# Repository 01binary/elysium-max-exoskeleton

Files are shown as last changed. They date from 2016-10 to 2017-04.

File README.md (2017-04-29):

# Elysium Max Exoskeleton
A full-scale replica of the exoskeleton frame worn in the movie Elysium (2013) by Max Da Costa. A few parts differ from their screen appearance to introduce interesting detail but most have been modeled based on photographs and verified from several different angles.

> All STL/OBJ exports use millimeter units. Build volume is 5,592,770 mm^3.

* [Parts are viewable on GitHub](https://github.com/01binary/elysium-max-exoskeleton/blob/master/print/HipRight.stl).
* Instructions for building are included: [Default (Light)](https://github.com/01binary/elysium-max-exoskeleton/raw/master/instructions/assembly%20instructions.pdf) | [Hackaday (Dark)](https://github.com/01binary/elysium-max-exoskeleton/raw/hackadayinstructions/instructions/assembly%20instructions.pdf)
* [Follow the project on Hackaday](https://hackaday.io/project/19830-elysium-max-exoskeleton).
* [See the build log on Replica Prop Forum](http://www.therpf.com/showthread.php?t=212832).
* Interested in contributing? Fork or see the project tasks [here](https://github.com/01binary/elysium-max-exoskeleton/projects/1).

--------

* `print` - contains STL exports of individual parts
* `instructions` - contains a PDF with build instructions
    * `src` - source InDesign file w/links used to export the instructions PDF
* `assembled` - contains high-poly STL and OBJ exports for the assembled exoskeleton
* `src` - contains Autodesk Inventor parts (.ipt) and assemblies (.iam)
    * `Assemblies` - contains assemblies
        * `Pistons` - contains assemblies for each unique piston pair
    * `External` - contains parts modeled after existing real-world objects so that they can be referenced in Exoskeleton assembly
    * `Pistons` - contains piston parts
    * `Design` - contains original drawings used at starting stage of the project
* `render` - contains 3D renders to show assembled parts at a glance
* `view` - contains low-poly OBJ export of the entire exoskeleton with ambient occlusion and UV coordinates (for real-time 3D rendering)
* `build` - contains photographs to show assembled parts at a glance
* `references` - contains reference photographs used to model all parts in this project

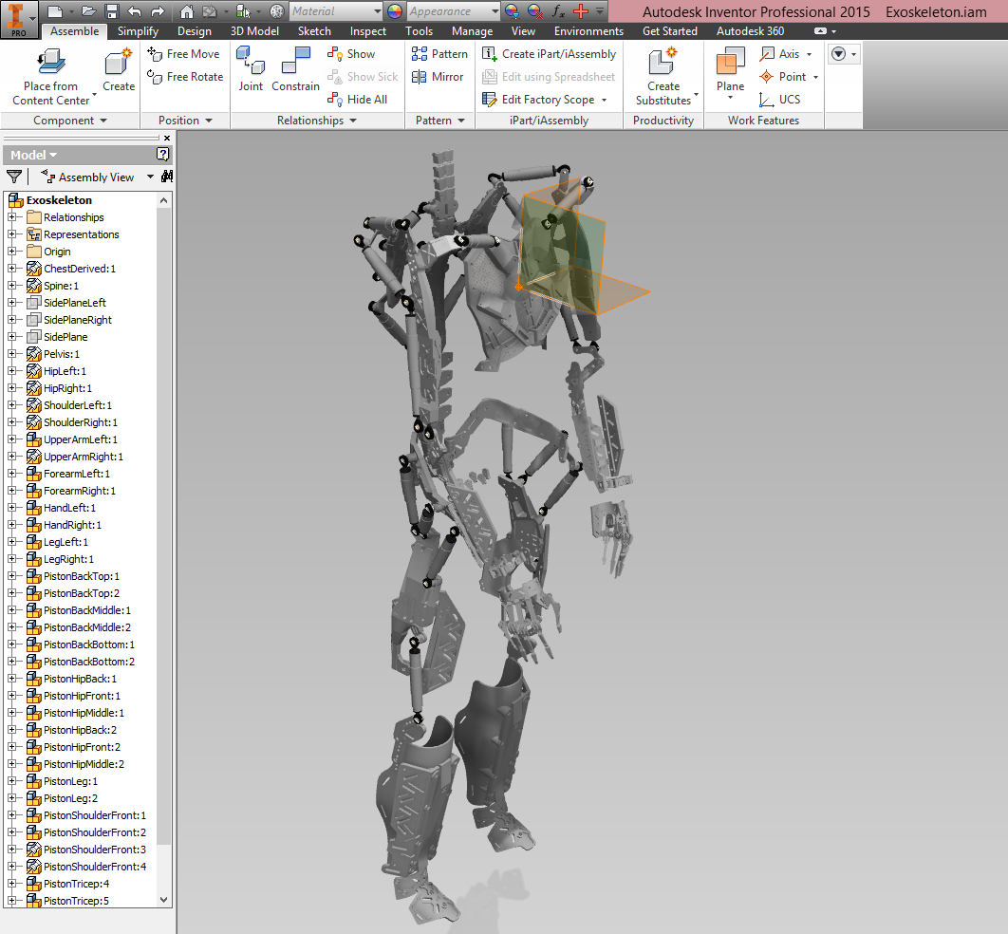
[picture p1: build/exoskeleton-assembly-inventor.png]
inventor Inventor Assembly


| Front | Side | Back |
|---|---|---|
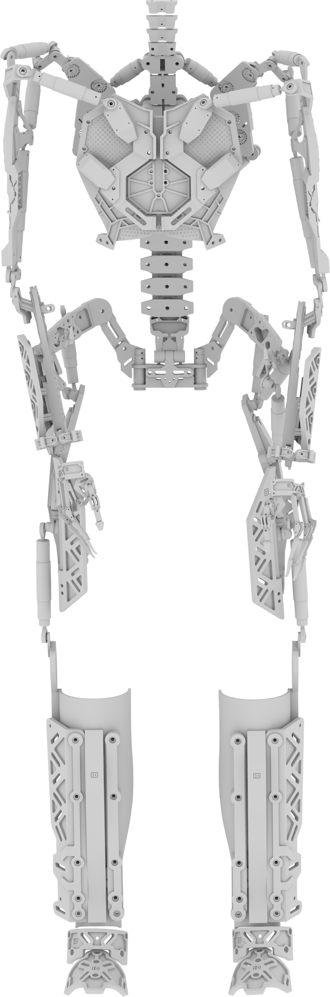
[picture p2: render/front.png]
front Front View
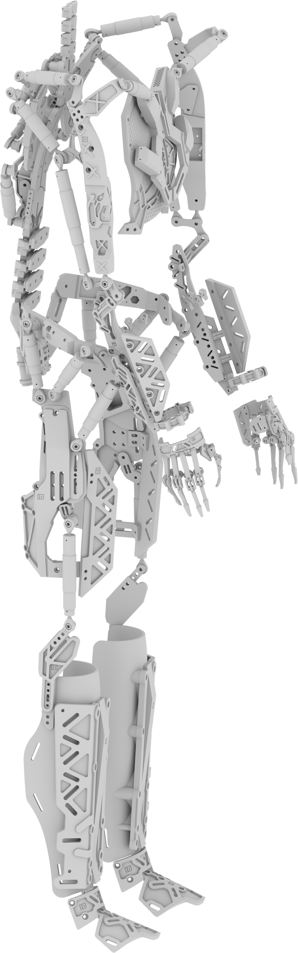
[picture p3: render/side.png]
side Side View
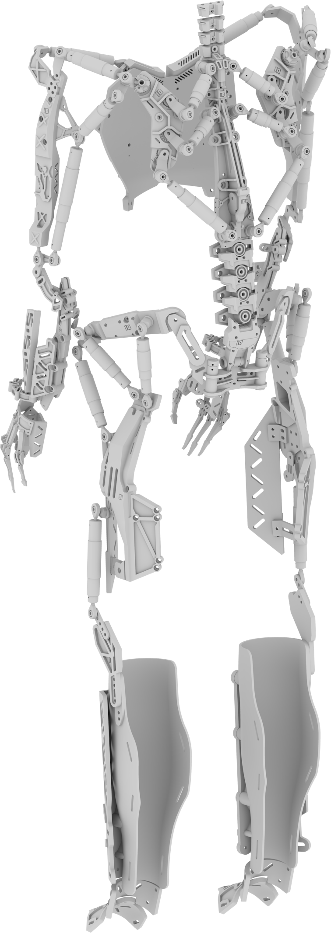
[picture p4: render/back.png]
back Back View
| |  | |

3D Printed with machined pistons:

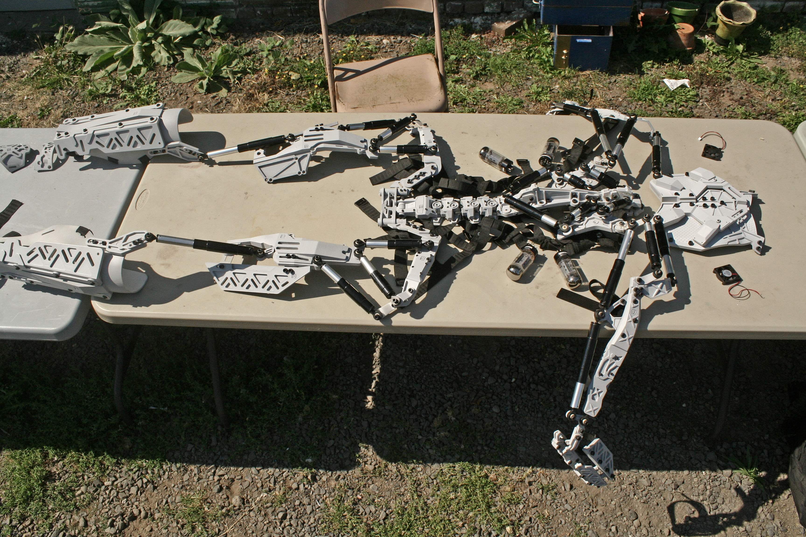
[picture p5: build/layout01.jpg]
layout Layout

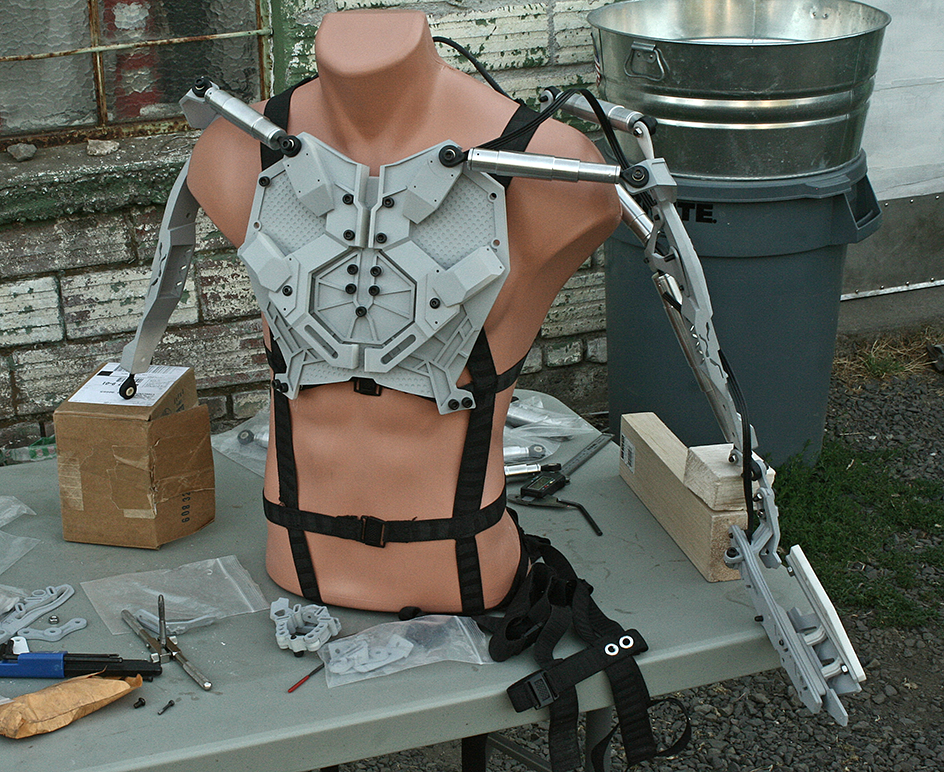
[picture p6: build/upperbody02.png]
front-mounted Front Mounted

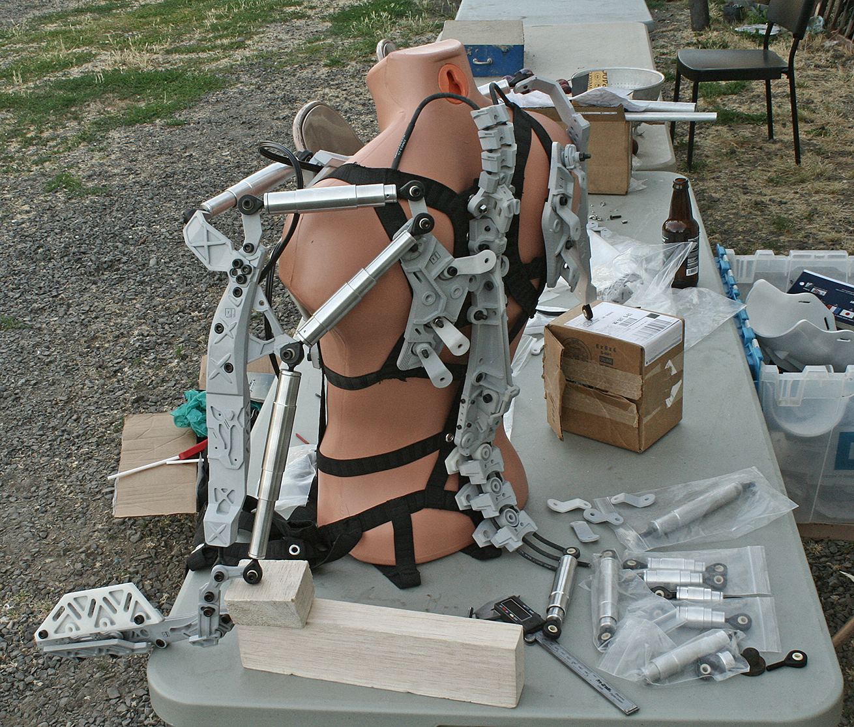
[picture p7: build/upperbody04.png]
back-mounted Back Mounted


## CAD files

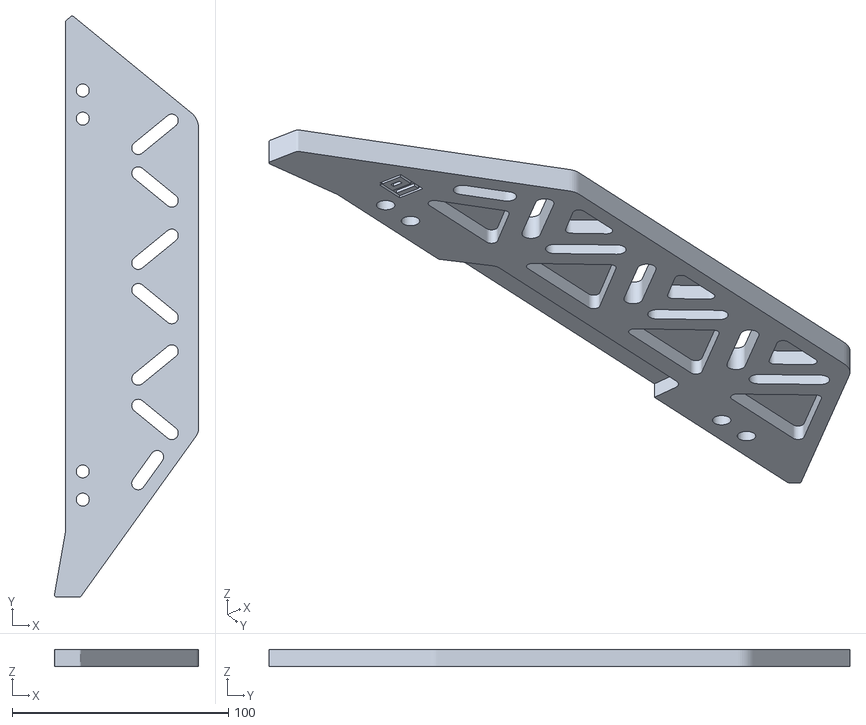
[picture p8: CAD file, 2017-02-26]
print/HipShockPlateRight.stl
66.6 x 268.4 x 8.00

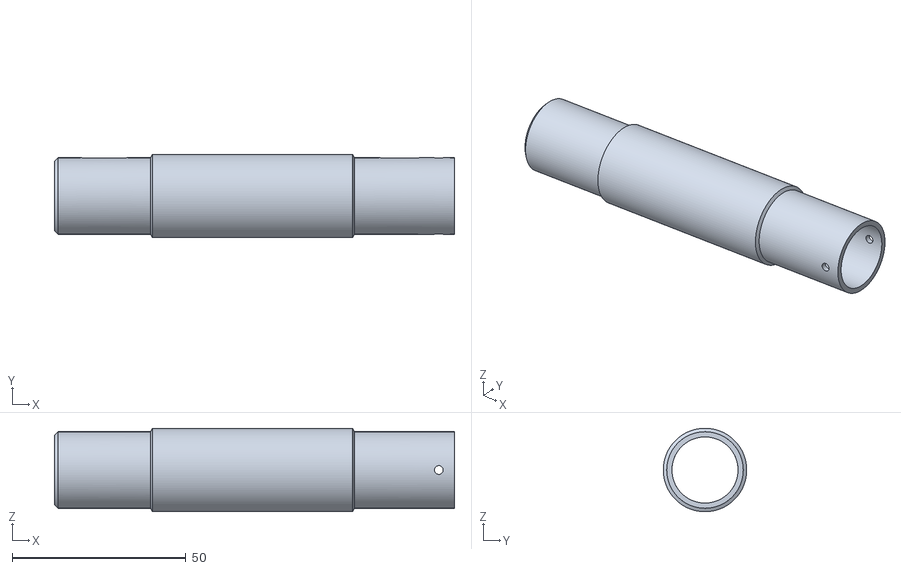
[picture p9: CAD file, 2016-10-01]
print/Pistons/PistonShoulderBackBody.stl
115.0 x 24.0 x 24.0

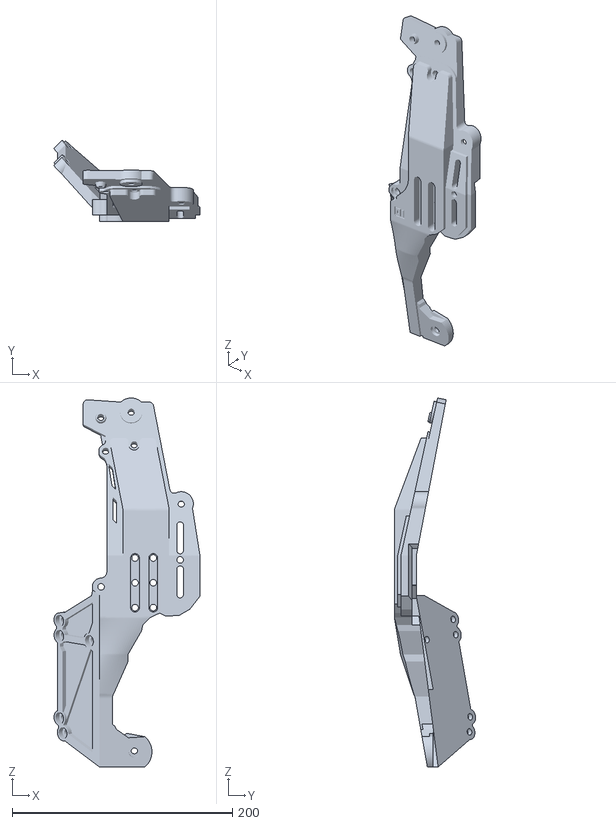
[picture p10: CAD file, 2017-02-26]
print/HipRight.stl
132.5 x 73.8 x 334.9

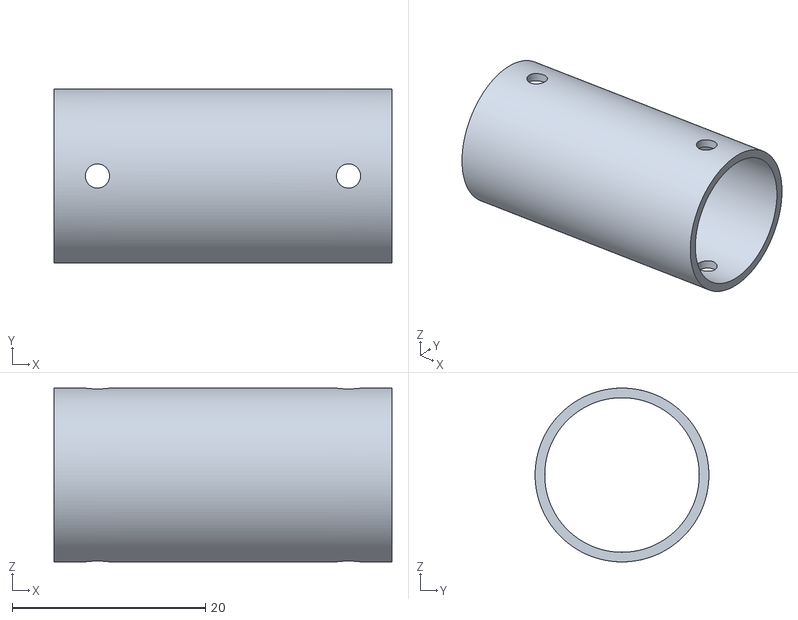
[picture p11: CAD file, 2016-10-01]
print/Pistons/PistonBackMiddleShaft.stl
35.0 x 18.0 x 18.0

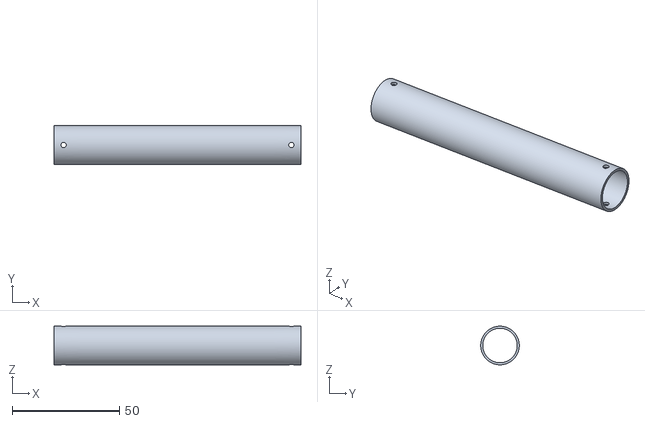
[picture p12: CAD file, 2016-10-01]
print/Pistons/PistonShoulderBackShaft.stl
115.0 x 18.0 x 18.0

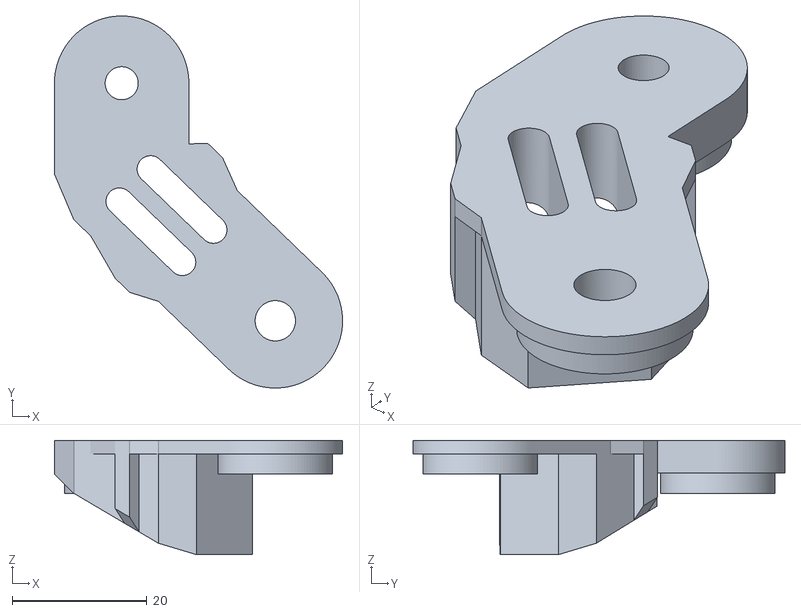
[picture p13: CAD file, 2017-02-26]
print/HipPistonConnectorRight.stl
42.8 x 55.3 x 17.0

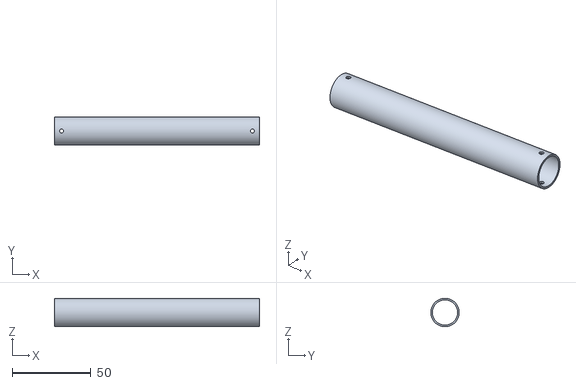
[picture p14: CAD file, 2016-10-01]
print/Pistons/PistonTricepShaft.stl
130.0 x 18.0 x 18.0

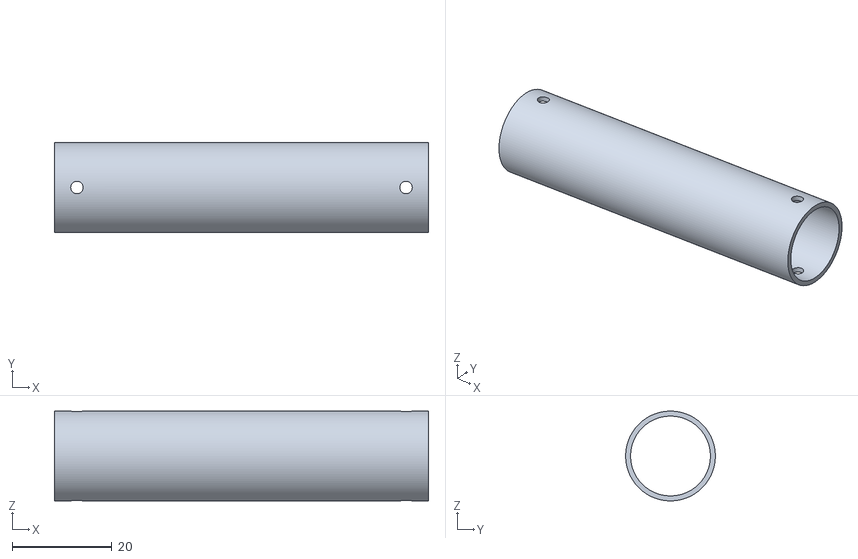
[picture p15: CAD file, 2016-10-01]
print/Pistons/PistonHipMiddleShaft.stl
75.0 x 18.0 x 18.0

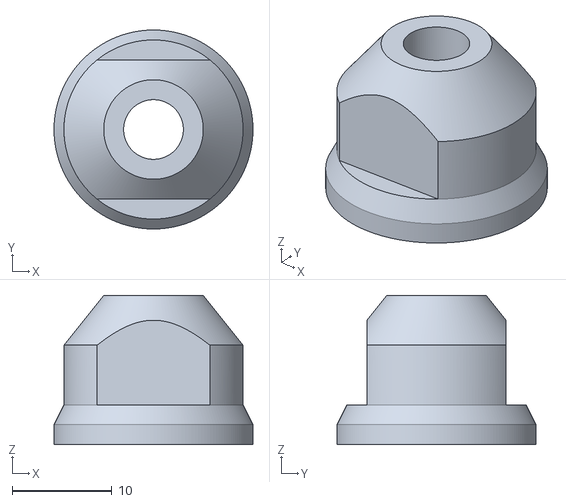
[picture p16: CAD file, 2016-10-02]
print/SpacerShort.stl
20.0 x 20.0 x 15.0

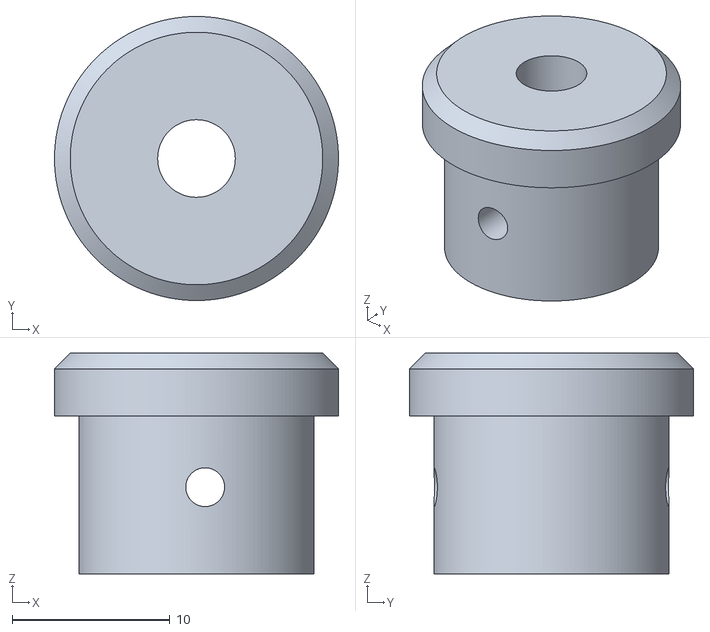
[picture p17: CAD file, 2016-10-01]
print/Pistons/PistonShaftCap.stl
18.0 x 18.0 x 14.0

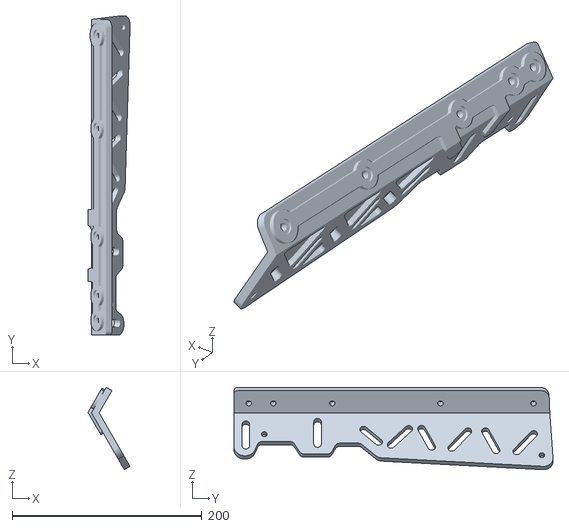
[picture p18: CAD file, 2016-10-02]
print/ShinShockPlateRight.stl
44.4 x 336.0 x 86.8

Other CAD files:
instructions/src/links/piston drawing.dwg
src/Design/Shin.dwg
src/Design/InsideForearm.dwg
print/HipShockPlateLeft.stl
src/Design/Forearm.dwg
src/Design/Shoulder.dwg
src/Design/ShoulderConnector.dwg
instructions/images/src/Chest.ipn
instructions/images/src/ForearmLeft.ipn
instructions/images/src/Hand.ipn
instructions/images/src/Hip.ipn
instructions/images/src/Pelvis.ipn
instructions/images/src/Piston.ipn
instructions/images/src/Shoulder.ipn
instructions/images/src/Spine.ipn
instructions/images/src/UpperArm.ipn
print/BackConnector.stl
print/BackSideConnector.stl
print/ChestPlateLeft.stl
print/ChestPlateRight.stl
print/DistPhalangeIndex.stl
print/DistPhalangeMiddle.stl
print/DistPhalangePinky.stl
print/DistPhalangeRing.stl
print/DistPhalangeThumb.stl
print/ElbowConnectorLeft.stl
print/ElbowConnectorLinkLeft.stl
print/ElbowConnectorLinkRight.stl
print/ElbowConnectorRight.stl
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

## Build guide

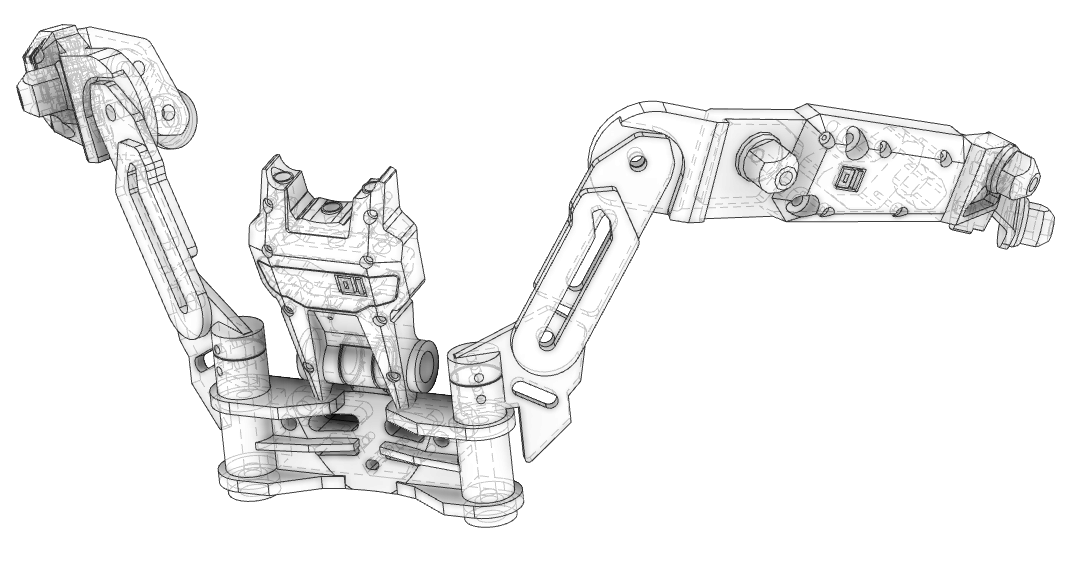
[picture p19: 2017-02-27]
instructions/images/pelvis/pelvis-view-corner.png

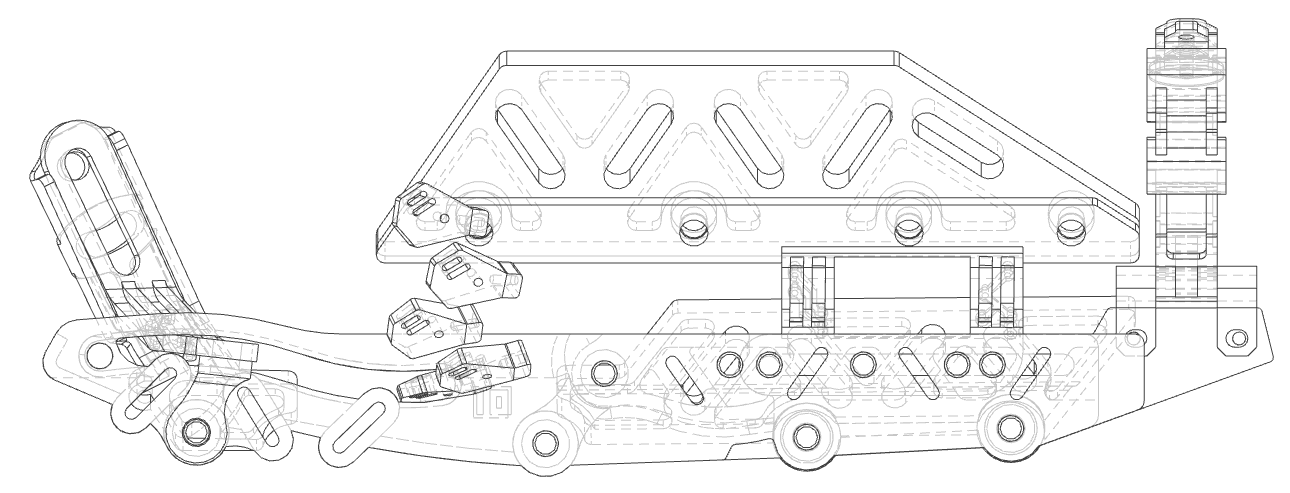
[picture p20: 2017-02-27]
instructions/images/forearm/forearm-view-left.png

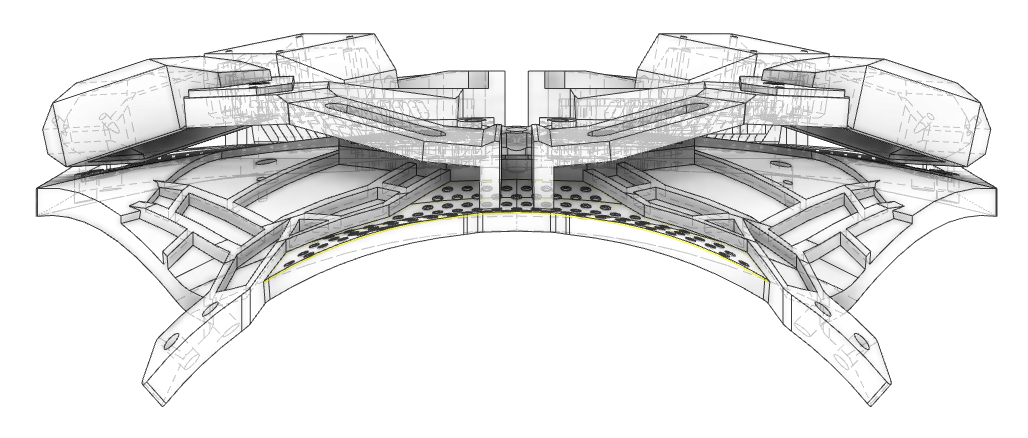
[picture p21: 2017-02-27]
instructions/images/chest/chest-view-bottom.png

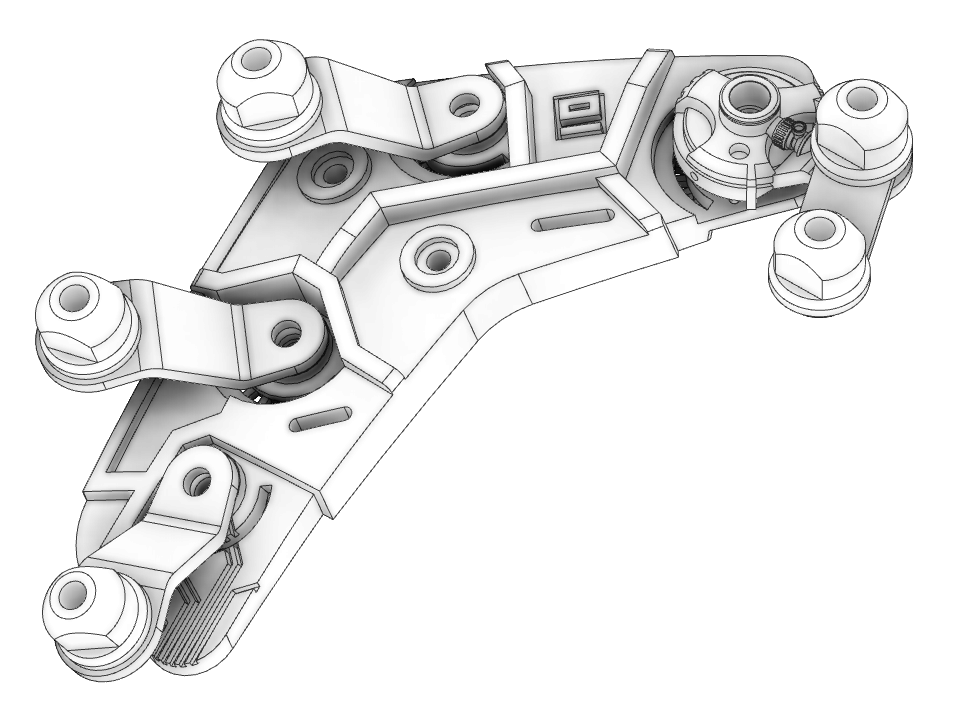
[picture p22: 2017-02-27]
instructions/images/shoulder/shoulder-view-corner.png

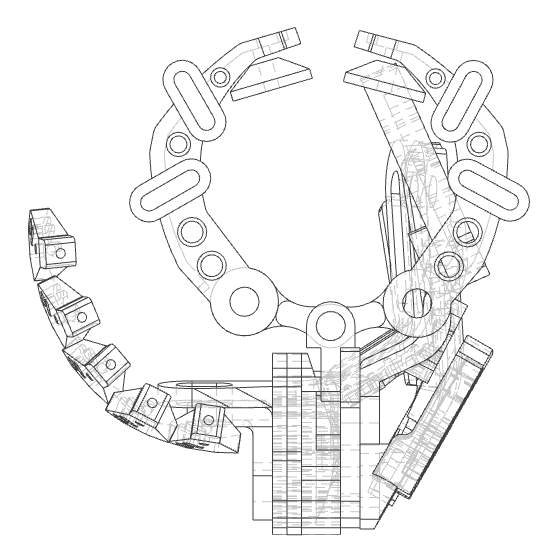
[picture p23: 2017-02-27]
instructions/images/forearm/forearm-view-front.png

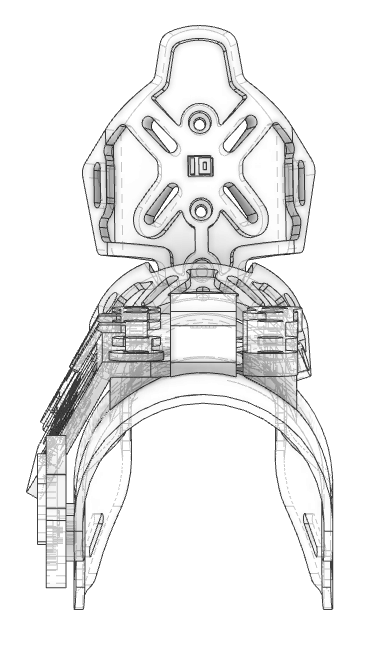
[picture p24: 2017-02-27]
instructions/images/leg/leg-view-top.png

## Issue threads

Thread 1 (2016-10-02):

SpineCoverLeft/Right don't fit in Spine Assembly

01binary, 2016-10-02:
One or more parts included in Spine Assembly must have their versions mixed up (due to partial restore from backup after file corruption). Axis and Plane constraints in Spine Assembly are broken because of this, and SpineCoverLeft/SpineCoverRight cannot be constrained.

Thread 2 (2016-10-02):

SpacerShort needs reference verification

01binary, 2016-10-02:
There was a mix-up with SpacerShort file version and original file was lost (had to be re-created using SpacerLong). Use photo references to verify what length SpacerShort needs to be. For now left at 6mm height (SpacerLong is 10mm).

01binary, 2016-10-02:
Verified SpacerShort to be 6mm high (from platform bevel to top taper) by overlaying both 3D models over `6mm-bolts.jpg` reference and lining up Perspective projection.

Closed 2016-10-02.

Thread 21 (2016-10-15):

Rename Leg Assembly Right to Left and vice versa

01binary, 2016-10-15:
Rename Leg assembly because it was originally named from the wrong reference point.

Closed 2016-10-15.

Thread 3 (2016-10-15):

Verify SpacerShort length

01binary, 2016-10-15:

01binary, 2016-10-15:
Closed in original issue #2.

Closed 2016-10-15.

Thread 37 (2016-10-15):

Fix SpineCover Left/Right in Spine Assembly

01binary, 2016-10-15:

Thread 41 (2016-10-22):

Fix logo direction on switched leg parts.

01binary, 2016-10-22:

Closed 2017-02-26.

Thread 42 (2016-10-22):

Order long and short spacers from Fineline

01binary, 2016-10-22:
short spacers

2 - for upper neck
2 - for spine top
4 - for shoulder connectors
4 - for pelvis wings
6 - for shoulder blades
2 - for legs
6 - for hips
total: 26

2 - extra

long spacers
2 - for the spine bottom
total: 2

2 - extra

Let’s get 2 copies of all plus extras.

26 x 2 + 2 short, 6 long = 54 short, 6 long

01binary, 2016-10-22:
Quote in flight, soft and hard metal.

01binary, 2016-10-24:
~ $1000

https://www.firstcut.com/FirstQuote.aspx?p=1374920htia
https://www.firstcut.com/FirstQuote.aspx?p=137491956an

01binary, 2016-10-25:
Ordered

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

Closed 2016-10-25.

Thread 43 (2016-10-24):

Order 4 more silicone buckets

01binary, 2016-10-24:
https://www.smooth-on.com/products/dragon-skin-10-medium/

https://www.smooth-on.com/distributor-regions/usa/

01binary, 2016-12-20:
Ordered 3x gallon size from Far West:
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

Closed 2016-12-20.

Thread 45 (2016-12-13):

Order final metal casting tools

01binary, 2016-12-13:
### Wax injector

- https://www.amazon.com/s/ref=nb_sb_noss?url=search-alias%3Daps&field-keywords=wax+injector+jewelry

### Propeller Mixer

- Series BN: http://www.cicpro.com/manufacturers/neptune-mixer/

### Jewelry Torch

- http://www.tmart.com/Smith-New-Jewelry-Welding-Torch-Kit-Mini-Gas-Torch-Soldering-with-5-Weld-Tips_p345912.html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

- https://jet.com/product/detail/0b51c8c1f2f749a7ba47c078cd298d16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

### Propane Tank

- Best gotten from store - https://www.amazon.com/s/ref=nb_sb_noss_2?url=search-alias%3Daps&field-keywords=propane+tank

### Sculpting Wax

- French - https://www.amazon.com/Sculpture-House-French-Modeling-Wax/dp/B00DQSF2KG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

Best gotten from Blick.

### Sand Sifter

01binary, 2016-12-17:
Still need propane tank and metal pan for the kiln for catching wax.

01binary, 2016-12-17:
Never mind, propane tank is a separate issue because the forge also needs one.

Closed 2016-12-17.

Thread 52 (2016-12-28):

Order 2 Wi-Fi power plugs to remotely control kiln and silicone vibrator.

01binary, 2016-12-28:
Ordered WOSUK from Amazon. Wifi app control.

https://www.amazon.com/WOSUK-Wifi-Socket-Electronics-Electrical/dp/B01MEBQQOO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

Closed 2016-12-29.

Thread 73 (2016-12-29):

Research investment shell cracking

01binary, 2016-12-29:

01binary, 2017-01-01:
"Make sure to melt the wax out completely at around 400 degrees then slowly bring it up to about 1000 - 1100 to completely bake the mold. "

01binary, 2017-01-16:
Cracked at 80 F in a pre-heated oven (starting around 75 F).

01binary, 2017-01-17:
http://scholarsmine.mst.edu/cgi/viewcontent.cgi?article=6002&context=masters_theses

01binary, 2017-01-17:
http://webcache.googleusercontent.com/search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

INVESTMENT CASTING Machinable Wax can be used for Investment Casting applications only if it can be flash fired out of the molds at a temperature of 1800 degrees F. The reason the high temperature is required is because the wax expands so much when going from a solid to a liquid that it will crack the ceramic shell unless it goes into that high temperature so quickly that the material will just disintegrate before this change occurs.

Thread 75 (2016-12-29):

Research wax vacuum and burnout ovens

01binary, 2016-12-29:
http://www.bestvaluevacs.com/3-2cf-vacuum-degassing-oven-stainless-steel-interior-4-individual-heated-shelves.html

01binary, 2016-12-30:
http://www.acrossinternational.com/Elite_c154.htm

01binary, 2016-12-30:
http://growershouse.com/across-international-accu-temp-vacuum-drying-oven-degassing-oven-0-9-cu-ft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

01binary, 2016-12-30:
Need 29 Hg

01binary, 2016-12-30:
http://www.gesswein.com/p-1618-heavy-duty-burnout-furnace.aspx

01binary, 2016-12-30:
http://www.gesswein.com/p-1624-programmable-burnout-furnaces.aspx

01binary, 2016-12-31:
http://www.ebay.com/itm/Thermo-Furnace-kiln-oven-F30424C-220V-1PH-ASH-Muffle-burn-out-TESTED-Huge-inside-/201766647449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

Seems like a perfect candidate.

01binary, 2016-12-31:
Ended up with http://www.ebay.com/itm/201763505950

Dimensions match, power options not too isoteric, more than enough temp, and programmable. Seems like good programming interface too.

01binary, 2017-01-04:
This video explains how to use:
https://www.youtube.com/watch?v=0nz5zfesaoc

Closed 2016-12-31.

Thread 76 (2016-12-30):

Laboratory degassing pump oil

01binary, 2016-12-30:
The vacuum pump for lab degasser ceases to run. Jon says no oil.

Edwards
Model RV3
Code A652-01-906
24kg Vacuum Pump

Oil:
Ultragrade 19

http://www.fluidxinc.com/vacoil-19-grade-vacuum-pump-oil-1-gallon/

01binary, 2016-12-30:
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

From good old SLC :1st_place_medal:

Closed 2016-12-30.

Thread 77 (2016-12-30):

Order mixer adapter for voltage converter

01binary, 2016-12-30:
Prop mixer comes with power supply that needs voltage stepped up from American wall socket. The inverter doesn't have a connection with ground (see picture below, only a 2-pronged connection without ground)

01binary, 2016-12-30:
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

NOOOOOOOO!!!!!

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

01binary, 2016-12-30:
100 Watts is the one I bought
Unit is 240V 6A

A = W/V
W = A * V = 6 * 240 * PF = 1440 * PF (1500W?)

01binary, 2017-01-01:
Got the 2000W inverter as above.

Closed 2016-12-31.

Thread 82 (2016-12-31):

Order welding goggles

01binary, 2016-12-31:

01binary, 2017-01-01:
Same ones being sold at Airgas bug with spikes.

https://www.amazon.com/gp/product/B00YAL1UO0/ref=oh_aui_detailpage_o03_s00?ie=UTF8&psc=1

Closed 2017-01-01.

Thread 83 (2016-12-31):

Order tank adapters for the torch

01binary, 2016-12-31:
Airgas

01binary, 2017-01-01:
Ended up ordering online. Torch:
https://www.amazon.com/Little-Torch-Tips-Box-Acetylene/dp/B001DZIML0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

Propane regulator:
https://www.amazon.com/Miller-Electric-249-500B-Propane-Regulator/dp/B007I6SKBK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

Oxygen regulator:
https://www.amazon.com/Smith-Little-Preset-Regulator-249-499B/dp/B007I6SK7O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

Closed 2017-01-01.

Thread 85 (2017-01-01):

Order replacement vacuum chamber

01binary, 2017-01-01:
Chamber imploded due to improper cleaning from silicone. While under vacuum, it slid sideways and the onrush of air bent the chamber. Always clean from silicone before degassing again!

Order a new chamber:
http://www.bestvaluevacs.com/bvv-1g-flat-ss.html

01binary, 2017-01-01:
Ordered, arriving Wednesday.

Closed 2017-01-01.

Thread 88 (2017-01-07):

Get cooling system for propeller mixer

01binary, 2017-01-07:
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

01binary, 2017-01-08:
Turns out didn't need cooling because that's for using with vacuum chambers and many hours of non-stop operation. Motor didn't run because the voltage from inverter was wrong. Thanks Isaac!

Closed 2017-01-08.

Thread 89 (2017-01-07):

Fix BlueM vacuum pump

01binary, 2017-01-07:
Edwards
Model RV3
Code A652-01-906
24kg Vacuum Pump

01binary, 2017-01-16:
Ordered new vacuum oven with pump instead.

Closed 2017-01-16.

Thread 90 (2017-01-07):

Find out why torch regulators don't fit cylinders

01binary, 2017-01-07:
SMITH LITTLE TORCH PRESET REGULATOR FOR FUEL PROPANE - MAPP - DISPOSABLE TANK REGULATOR 249-500B- Regulator for Disposable Cylinder- Fits "B" 9/16" LH FUEL Hose Left Hand Thread Fitting- Regulator is designed for use with 14 ounce disposable cylinders, the outlet pressure is 4-8 PSIG Outlet Pressure NOVEL Product # 2003-2102

01binary, 2017-01-07:
Oops, they are colored opposite way. Red tank gets green regulator and blue tank gets red regulator. Opposite thread.

Closed 2017-01-07.

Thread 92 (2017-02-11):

Research silicone molds that don't crack patterns on demold

01binary, 2017-02-11:
Current silicone molds worked with Machinable Wax which is tough and doesn't fracture when pulling out of the mold. The new pattern wax that's supposed to help with investment shells cracking is more fragile and molds have to be modified somehow.

01binary, 2017-03-24:
All edge cases appear to have been found...

- Cuts to release features when silicone density is high
- Careful cuts to release intricate features
- Open 1-piece mold if possible, outside part to be cut off after metal casting is made

Closed 2017-03-24.

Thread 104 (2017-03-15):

Wax cast Forearm Clamp

01binary, 2017-03-15:
A new mold for Forearm Clamp is being made. Two previous molds didn't yield expected results. Wax cast after the mold is done.

01binary, 2018-01-24:
Wax cast looks good, this task was created to track silicone mold modifications to get a perfect wax cast, and it's perfect now.

Closed 2018-01-24.

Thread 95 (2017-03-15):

Time wax cooling time for repeatable demold

01binary, 2017-03-15:
Find how long it takes for hot wax to cool down enough to de-mold while keeping high enough core temperature to not crack when it's being taken out.

01binary, 2017-03-20:
It takes 2 hours for the largest part measured so far to cool down. Recommend separating molds from the tray after 45 minutes as it's a major cause of cracking afterwards.

Closed 2017-03-20.

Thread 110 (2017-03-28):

Wax cast Lower Forearm

01binary, 2017-03-28:
https://github.com/01binary/elysium-max-exoskeleton/blob/master/print/LowerForearm.stl

01binary, 2018-01-24:
Fast-tracked using later cutting

Closed 2018-01-24.

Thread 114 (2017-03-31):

Research UltraVest

01binary, 2017-03-31:
Max temp is 1400 F.
Add investment into de-ionized water.
Wet for 30 seconds with wire mixer.
Mix for 3 minutes with mechanical mixer.
Vacuum for 3 minutes, remixing once.
Do not pour directly onto pattern to avoid breaking it.
Requires 1" clearance over the pattern or more.
Vacuum after filling for 1.5 minutes while vibrating.
Immediately transfer to vibration free area for drying.
Cure is 6 hours. If cracks, cover with plastic.
Need plastic bag for investment.

Consult charts for investment and water by volume and weight.

Need a nice mixing bowl for the investment & degassing.
Plastic bag for covering investment
Bucket for washing tools and misc, since we can't do it in sink
Mechanical mixer

http://www.ransom-randolph.com/PDFs/Application%20Instructions/03%20Jewelry/Ultra-Vest%20Investment%20Application%20Instructions.pdf

Closed 2017-03-31.

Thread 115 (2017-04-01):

Assembly Instructions for Print

01binary, 2017-04-01:
- [ ] High-res images (1200ppi - 600dpi). Consider rendering with different colors.
- [ ] Tighten up color profiles. Ensure all images are color managed for U.S. Web Coated SWOP2, transparency effects are in appropriate color space, and all colors used are process colors.
- [ ] Get options and quotes from online print suppliers for Perfect Bind, heavy page stock, and all-black pages.

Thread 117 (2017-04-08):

Investment cast Upper Arm Shoulder Right

01binary, 2017-04-08:

01binary, 2018-01-24:
No longer tracking investment casts with tasks, too granular

Closed 2018-01-24.

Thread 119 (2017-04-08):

Investment cast Lower Forearm

01binary, 2017-04-08:
https://github.com/01binary/elysium-max-exoskeleton/blob/master/print/LowerForearm.stl

01binary, 2018-01-24:
Fast-tracked using later cutting

Closed 2018-01-24.

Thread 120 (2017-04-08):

Wax cast Elbow Connector Right

01binary, 2017-04-08:
https://github.com/01binary/elysium-max-exoskeleton/blob/master/print/ElbowConnectorRight.stl

01binary, 2018-01-24:
Fast-tracked CNC machining

Closed 2018-01-24.

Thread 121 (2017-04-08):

Wax cast Elbow Connector Left

01binary, 2017-04-08:
https://github.com/01binary/elysium-max-exoskeleton/blob/master/print/ElbowConnectorLeft.stl

01binary, 2018-01-24:
Fast-tracked CNC machining

Closed 2018-01-24.

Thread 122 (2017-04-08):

Wax cast Forearm Base

01binary, 2017-04-08:
https://github.com/01binary/elysium-max-exoskeleton/blob/master/print/ForearmBase.stl

01binary, 2018-01-24:
Fast-tracked using later cutting

Closed 2018-01-24.

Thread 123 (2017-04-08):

Wax cast Forearm Inner Base

01binary, 2017-04-08:
https://github.com/01binary/elysium-max-exoskeleton/blob/master/print/ForearmInnerBase.stl

01binary, 2018-01-24:
Fast-tracked using later cutting

Closed 2018-01-24.

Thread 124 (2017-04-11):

Research casting surface quality issues

01binary, 2017-04-11:
- [ ] Try 535 alloy
- [ ] Try 356 alloy
- [ ] Try more metal volume in a cone entrance
- [ ] Try adding more air escape vents
- [ ] Try using degasser differently
- [ ] Try using conditioner differently
- [ ] Temperature control with pyrometer
- [ ] Timing control with a multi-timer
- [ ] Vacuum casting

01binary, 2017-04-11:
Try ordering from Pacific Cast Products: http://www.pacificcastproducts.com/Pages/AluminumAlloys.aspx

01binary, 2017-04-20:
Requested a quote for 535 alloy, which seems like the best fit for the application.

01binary, 2017-04-22:
Looks like I need a vacuum casting rig. Got started on it by buying vacuum casting flasks (perforated).

01binary, 2017-04-22:
http://buynow.metalsupermarkets.com/landing-page/?city=portland&gclid=CKiE86rBuNMCFQ2ffgodTZ0K6w

01binary, 2017-04-22:
http://www.westcoastmet.com/

01binary, 2017-04-22:
http://www.eastsidesteel.com/

01binary, 2017-04-22:
http://www.foundrystuff.com/contact.html

01binary, 2017-04-22:
Get this for temp control:
http://mifco.com/shop/pyrometers/replacement-12-thermocouple-tip/

01binary, 2017-04-22:
https://www.google.com/search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,-122714546,5971&tbm=lcl&rldimm=15412113356342456738&ved=0ahUKEwiw0erqjbnTAhURxGMKHb2cBkUQvS4IYzAC&rldoc=1&tbs=lrf:!2m1!1e2!2m1!1e3!3sEAE,lf:1,lf_ui:2

01binary, 2017-04-22:
https://www.google.com/search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,-122559047,509&tbm=lcl&rldimm=12746759637466513188&ved=0ahUKEwivxpnRkLnTAhUCwGMKHf21AWkQvS4ITTAB&rldoc=1&tbs=lrf:!2m1!1e2!2m1!1e3!3sEAE,lf:1,lf_ui:2

01binary, 2017-06-19:
Timing, vacuum casting, and better metal stock solved it.

Closed 2017-06-19.

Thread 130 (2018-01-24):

Design vacuum flask and chamber for HipLeft and HipRight

01binary, 2018-01-24:

01binary, 2018-01-27:
Too much work, going to order ($4k) instead from ProtoLabs.

Closed 2018-01-27.

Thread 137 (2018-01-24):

Shoot a complete video on all parts of investment casting process

01binary, 2018-01-24:
Steps

1. Design, produce and finish the model
2. Design and produce silicone mold
3. Cast and prepare the wax model
4. Invest the wax model and perform burnout
5. Vacuum metal casting

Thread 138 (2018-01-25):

Create 3.5 flask fixture

01binary, 2018-01-25:
* Get pipe with 3.5" inside diameter from Eastside Steel or Clackamas Steel
* Weld and machine the fixture
* Apply refractory if necessary

01binary, 2018-01-27:
Also need to think about pieces required to build casting boxes for chest base, chest left right and hip left right. Basically, something big like 14".

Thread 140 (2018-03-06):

Next batch

01binary, 2018-03-06:
next casting batch

-- existing molds

forearm clamp - 2+2
forearm clamp link - 2+2
elbow connector underlink left - the 90 angle - 1+1
elbow connector underlink right 1+1
elbow sub connector left -- the angle with ridges 1+1
elbow sub connector right 1+1

-- new molds
chest left
chest right

-- new flasks
chest left
chest right

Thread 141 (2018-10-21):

Pelvis Mount Stem holes not aligned

01binary, 2018-10-21:
Report from https://www.thingiverse.com/thing:2205658/comments/#comment-2028876.

It turns out Pelvis Mount Stem doesn't have a cut deep enough to allow Pelvis Mount to be inserted and align the mounting holes.

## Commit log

2016-09-27 Add Inventor Parts
    [ArmLeft.iam, ArmRight.iam, BackConnector.ipt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]
2016-10-01 Add Piston STL Exports
    [PistonBackBottomBody.stl, PistonBackBottomShaft.stl, PistonBackMiddleBody.stl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]
2016-10-01 Move Piston Exports to Subfolder
    [PistonBackBottomBody.stl, PistonBackBottomShaft.stl, PistonBackMiddleBody.stl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]
2016-10-01 Add More Print Exports
    [BackConnector.stl, BackSideConnector.stl, ChestPlateLeftDerived.stl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]
2016-10-01 Remove Corrupted Assemblies
    [ArmLeft.iam, ArmRight.iam, FootLeft.iam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]
2016-10-01 Renamed Derived Exports and Updated Readme
    [ChestPlateLeft.stl, ChestPlateRight.stl, VacuumTubeHolder.stl]
2016-10-02 Add Piston Assemblies, Quick Fixes for Parts
    [PistonBackBottom.iam, PistonBackMiddle.iam, PistonBackTop.iam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]
2016-10-02 Move Assemblies to Subfolder
    [Chest.iam, ChestDerived.iam, ChestPlateLeftDerived.ipt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]
2016-10-02 Add UpperArm Assemblies
    [UpperArmLeft.iam, UpperArmRight.iam]
2016-10-02 Add Forearm Assemblies
    [ForearmLeft.iam, ForearmRight.iam]
2016-10-02 Add Hand Assemblies
    [HandLeft.iam, HandRight.iam]
2016-10-02 Add Shoulder Assemblies, Rename ShoulderConnector Assembly
    [ShoulderConnector.iam, ShoulderLeft.iam, ShoulderRight.iam]
2016-10-02 Add Pelvis Assembly, Include Spacers in Shoulders
    [Pelvis.iam, ShoulderLeft.iam, ShoulderRight.iam]
2016-10-02 Add Spine Assembly, Fix SpineTopMiddleConnector Fitting
    [Spine.iam, SpineTopMiddleConnector.ipt]
2016-10-02 Added Extra Connector to Spine
    [Spine.iam]
2016-10-02 Add Hip Assemblies, Fix HipRight Parts, Fix SpacerShort
    [HipBottomConnectorLeft.ipt, HipBottomConnectorRight.ipt, HipLeft.iam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]
2016-10-02 Add NeckLinks to Spine
    [Spine.iam]
2016-10-02 Foot ShockPlates Tighter Bend Radius
    [FootShockPlate.ipt, FootShockPlate.stl, FootUpperShockPlate.ipt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]
2016-10-02 Add Leg Assemblies, Swap Left Right, Relax Shin Mouth Size
    [LegLeft.iam, LegRight.iam, ShinConnectorLeft.ipt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]
2016-10-02 Update SpacerShort STL Export
    [SpacerShort.stl]
2016-10-17 Initial commit of Exoskeleton assembly
    [Exoskeleton.iam]
2016-10-17 Exoskeleton spine section complete
    [Chest.iam, ChestDerived.iam, ChestPlateLeftDerived.ipt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]
2016-10-17 Exoskeleton left arm constraints
    [Exoskeleton.iam, UpperArmLeft.iam]
2016-10-17 Exoskeleton right arm constraints
    [Exoskeleton.iam, UpperArmRight.iam]
2016-10-17 Exoskeleton Assembly hooked up Upper Arms
    [Exoskeleton.iam, UpperArmLeft.iam, UpperArmRight.iam]
2016-10-17 Exoskeleton Assembly hooked up lower arms
    [Exoskeleton.iam]
2016-10-17 Exoskeleton upper body completed
    [UpperArmLeft.iam, UpperArmRight.iam]
2016-10-17 Exoskeleton Assembly completed
2016-10-17 Fix #34 Export Exoskeleton Assembly
2016-10-19 Insert table in readme
2017-02-26 Fix #41 logo direction on leg parts
    [HipLeft.iam, HipPistonConnectorRight.ipt, HipPistonConnectorRight.stl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]
2017-02-26 Update exoskeleton STL export
2017-02-27 Add instruction images
    [Chest.ipn, ForearmLeft.ipn, Hand.ipn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]
2017-02-28 Assembly instructions upper arm
2017-03-01 Complete the bulk of work on assembly instructions
2017-03-02 Completed assembly instructions and started fastener detail
2017-03-02 Export assembly instructions
2017-03-02 Update assembly instructions link to RAW
2017-03-05 Add piston drawing source
    [piston drawing.dwg]
2017-03-06 Re-export piston as AutoCAD 2000 dwg
    [piston drawing.dwg]
2017-03-06 Final hackaday assembly instructions
2017-03-06 Export assembly instructions PDF for hachackaday
2017-03-07 Finalize contest instructions and add LED lighting diagram
2017-03-19 Add units to print page
2022-03-20 Add rubber pad for backs of screws touching skin
    [Pad.ipt]
2022-03-20 Thicken elbow sub connector and make left right identical
    [ElbowSubConnector.ipt, ElbowSubConnectorLeft.ipt, ElbowSubConnectorRight.ipt]
2022-03-20 Reinforce upper arm shoulder and make movie accurate
    [UpperArmLeft.iam, UpperArmRight.iam, UpperArmShoulderLeft.ipt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]
2022-03-20 Update assemblies for replaced parts
    [Chest.iam, ChestDerived.iam, ForearmLeft.iam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]
